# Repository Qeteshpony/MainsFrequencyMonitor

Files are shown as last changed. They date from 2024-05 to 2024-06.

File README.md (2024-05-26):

# Mains Frequency Monitor

**Part of the board has mains voltage on it so it is dangerous to handle the board outside of a proper case while powered! It lies in your own responsibility to use proper safety precautions when working on this project!**



3D Render

[Hardware Documentation](https://qeteshpony.github.io/MainsFrequencyMonitor)

Single board solution to power an ESP32 and use it to measure the mains frequency through an optoisolator

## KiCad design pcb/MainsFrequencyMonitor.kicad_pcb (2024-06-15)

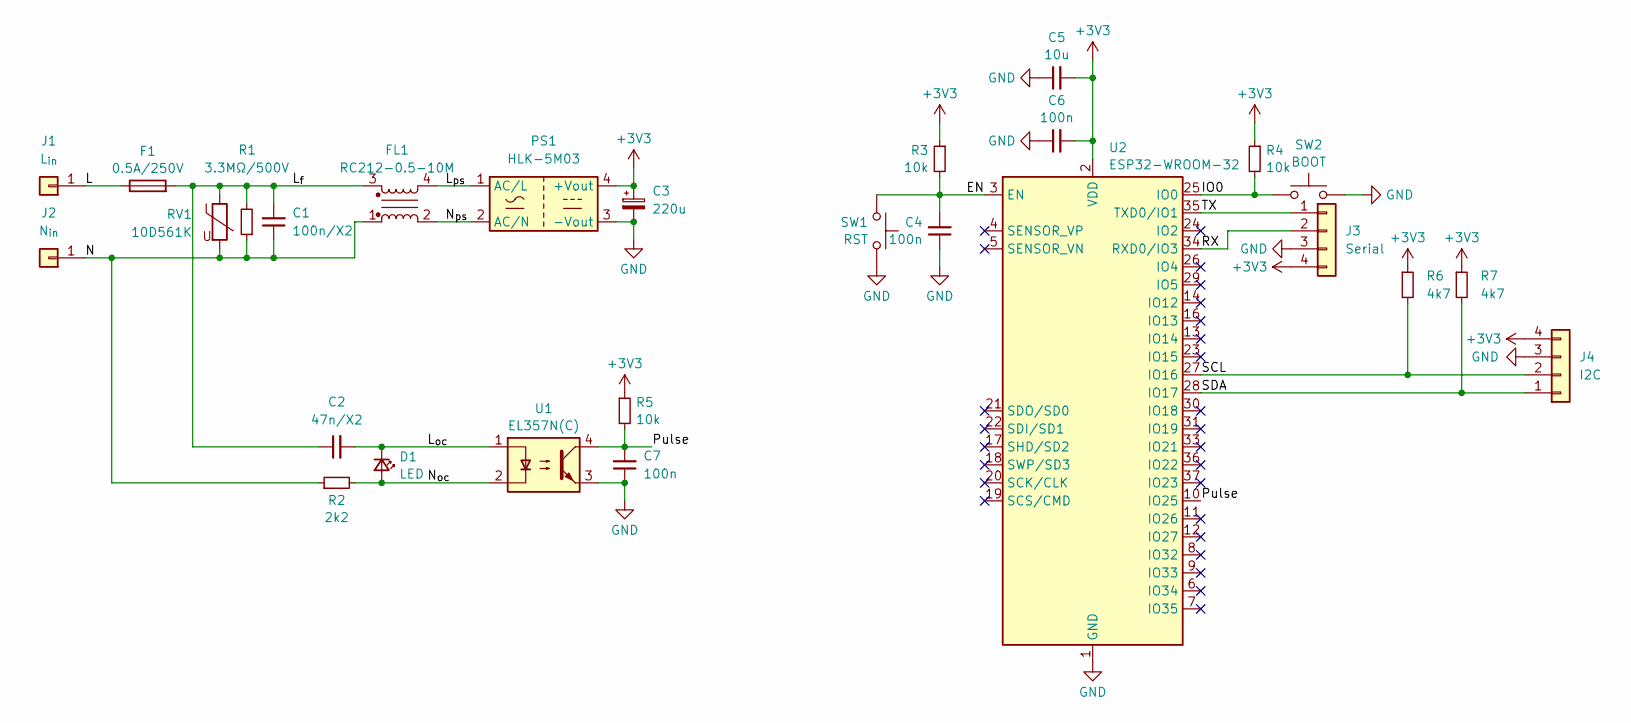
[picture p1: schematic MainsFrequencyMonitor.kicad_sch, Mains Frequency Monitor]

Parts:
C1: 100n/X2; C_Rect_L13.0mm_W5.0mm_P10.00mm_FKS3_FKP3_MKS4
C2: 47n/X2; C_Rect_L10.3mm_W5.7mm_P7.50mm_MKS4
C3: 220u; CP_Radial_D6.3mm_P2.50mm
C4, C6, C7: 100n; C_0603_1608Metric_Pad1.08x0.95mm_HandSolder; LCSC C14663
C5: 10u; C_0603_1608Metric_Pad1.08x0.95mm_HandSolder; LCSC C19702
D1: LED; LED_0805_2012Metric_Pad1.15x1.40mm_HandSolder; LCSC C84256
F1: 0.5A/250V; Fuseholder_TR5_Littelfuse_No560_No460
FL1: RC212-0.5-10M; Schaffner_RC212
J1: L_{in}; SolderWire-0.75sqmm_1x01_D1.25mm_OD3.5mm
J2: N_{in}; SolderWire-0.75sqmm_1x01_D1.25mm_OD3.5mm
J3: Serial; PinSocket_1x04_P2.54mm_Vertical
J4: I2C; JST_PH_B4B-PH-K_1x04_P2.00mm_Vertical; LCSC C157926
PS1: HLK-5M03; Converter_ACDC_Hi-Link_HLK-5Mxx
R1: 3.3MΩ/500V; R_Axial_DIN0207_L6.3mm_D2.5mm_P7.62mm_Horizontal
R2: 2k2; R_Axial_DIN0207_L6.3mm_D2.5mm_P7.62mm_Horizontal
R3, R4, R5: 10k; R_0603_1608Metric_Pad0.98x0.95mm_HandSolder; LCSC C25804
R6, R7: 4k7; R_0603_1608Metric_Pad0.98x0.95mm_HandSolder; LCSC C23162
RV1: 10D561K; RV_Disc_D12mm_W5.8mm_P7.5mm
SW1: RST; SW_Push_1P1T_XKB_TS-1187A; LCSC C318884
SW2: BOOT; SW_Push_1P1T_XKB_TS-1187A; LCSC C318884
U1: EL357N(C); SO-4_4.4x3.6mm_P2.54mm; LCSC C29981
U2: ESP32-WROOM-32; LCSC C503588

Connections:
+3V3: C3.1, C5.2, C6.2, J3.4, J4.4, PS1.4 (+Vout), R3.1, R4.1, R5.1, R6.1, R7.1, U2.2 (VDD)
/EN: C4.2, R3.2, SW1.2, U2.3 (EN)
/IO0: R4.2, SW2.1, U2.25 (IO0)
/L: F1.1, J1.1
/L_{f}: C1.2, C2.1, F1.2, FL1.3, R1.2, RV1.1
/L_{oc}: C2.2, D1.1 (K), U1.1
/L_{ps}: FL1.4, PS1.1 (AC/L)
/N: C1.1, FL1.1, J2.1, R1.1, R2.1, RV1.2
/N_{oc}: D1.2 (A), R2.2, U1.2
/N_{ps}: FL1.2, PS1.2 (AC/N)
/Pulse: C7.2, R5.2, U1.4, U2.10 (IO25)
/RX: J3.2, U2.34 (RXD0/IO3)
/SCL: J4.2, R6.2, U2.27 (IO16)
/SDA: J4.1, R7.2, U2.28 (IO17)
/TX: J3.1, U2.35 (TXD0/IO1)
GND: C3.2, C4.1, C5.1, C6.1, C7.1, J3.3, J4.3, PS1.3 (-Vout), SW1.1, SW2.2, U1.3, U2.1 (GND), U2.15 (GND), U2.38 (GND), U2.39 (GND)

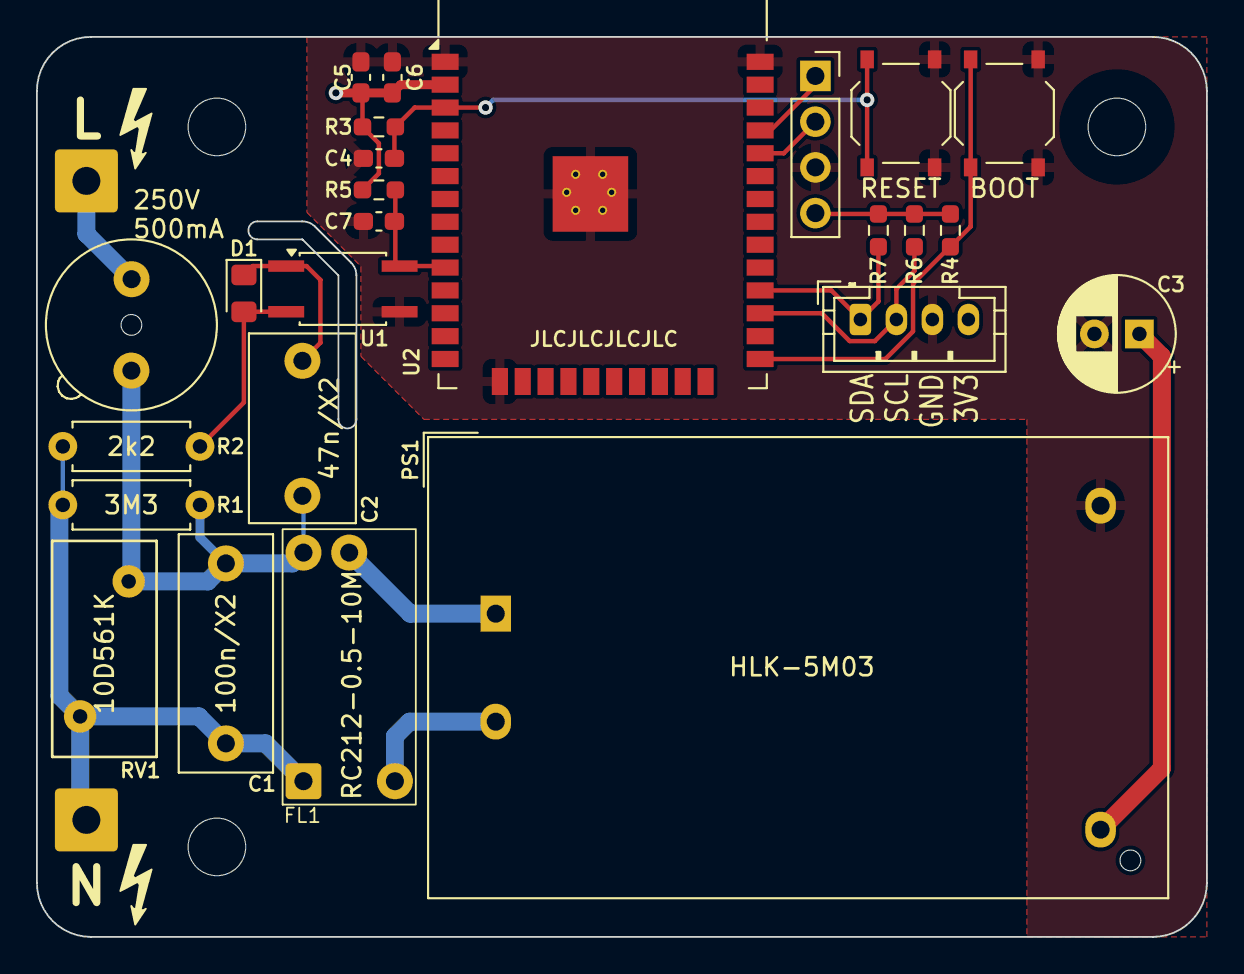
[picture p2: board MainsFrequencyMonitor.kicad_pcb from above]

Board: 2 copper layers, 65.0 x 50.0 mm, 27 parts (0 on the bottom side), 16 nets.

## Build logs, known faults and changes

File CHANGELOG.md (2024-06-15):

# Changelog

## [1.0.1](https://github.com/Qeteshpony/MainsFrequencyMonitor/compare/v1.0.0...v1.0.1) (2024-06-15)

### Bug Fixes

* add capacitor to optocouplers output ([5ca2877](https://github.com/Qeteshpony/MainsFrequencyMonitor/commit/5ca2877cb01ab06d6268d75e7aa877d265d5963e))

## [1.0.0](https://github.com/Qeteshpony/MainsFrequencyMonitor/compare/v1.0.0...v1.0.0) (2024-05-26)

### Miscellaneous Chores

* re-release after fixing config ([fd9009a](https://github.com/Qeteshpony/MainsFrequencyMonitor/commit/fd9009a7ea7f5308d8db38f59f342430c6b48b82))

## 1.0.0 (2024-05-26)

### Features

* initial commit ([c49b010](https://github.com/Qeteshpony/MainsFrequencyMonitor/commit/c49b0102f78f5d7bc4e2b697790dda48f1586ab4))

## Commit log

2024-05-26 feat: initial commit
    [MainsFrequencyMonitor.kicad_pcb, MainsFrequencyMonitor.kicad_sch]
2024-06-15 git: add kicad lock files to gitignore
2024-06-15 fix: add capacitor to optocouplers output
    Output of the optocoupler was not a smooth square wave form but had some voltage spikes. Adding a 100nF capacitor to the output solved this.
    [MainsFrequencyMonitor.kicad_pcb, MainsFrequencyMonitor.kicad_sch]
